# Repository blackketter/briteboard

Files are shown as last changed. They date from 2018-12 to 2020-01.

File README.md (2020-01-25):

# briteboard

BriteBoard is a Teensy 3.6-based keyboard with:

- 5x14 key matrix
- LCD display with capacitive touchscreen
- Audio amplifier and speaker
- USB host port for external mouse or keyboard
- Ambient light sensor

Runs the [britepad](https://github.com/blackketter/britepad) software.

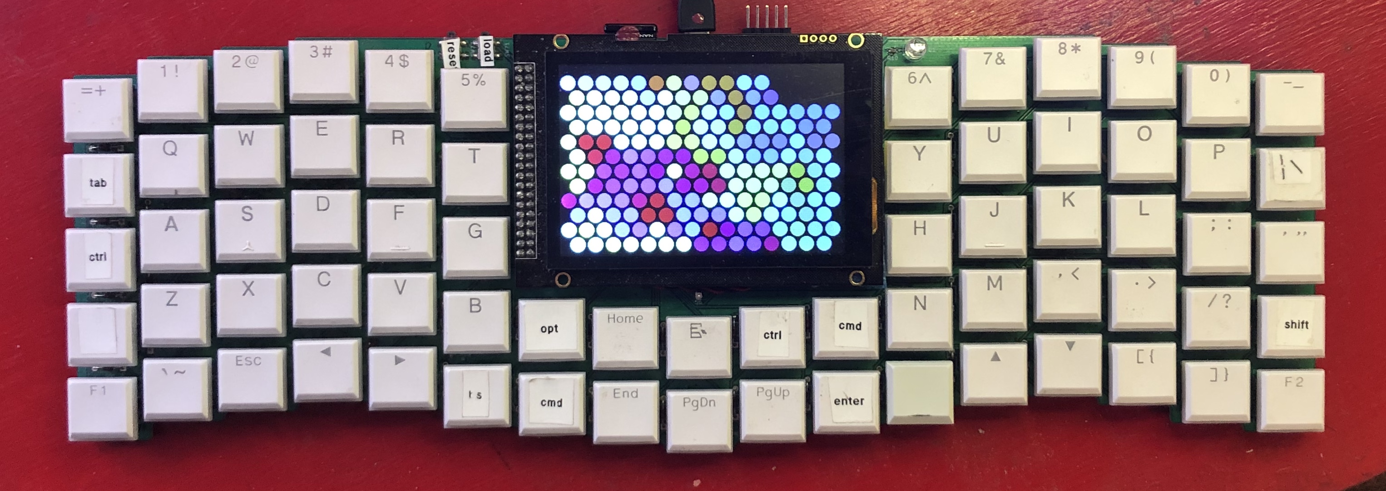
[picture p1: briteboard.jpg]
briteboard photo

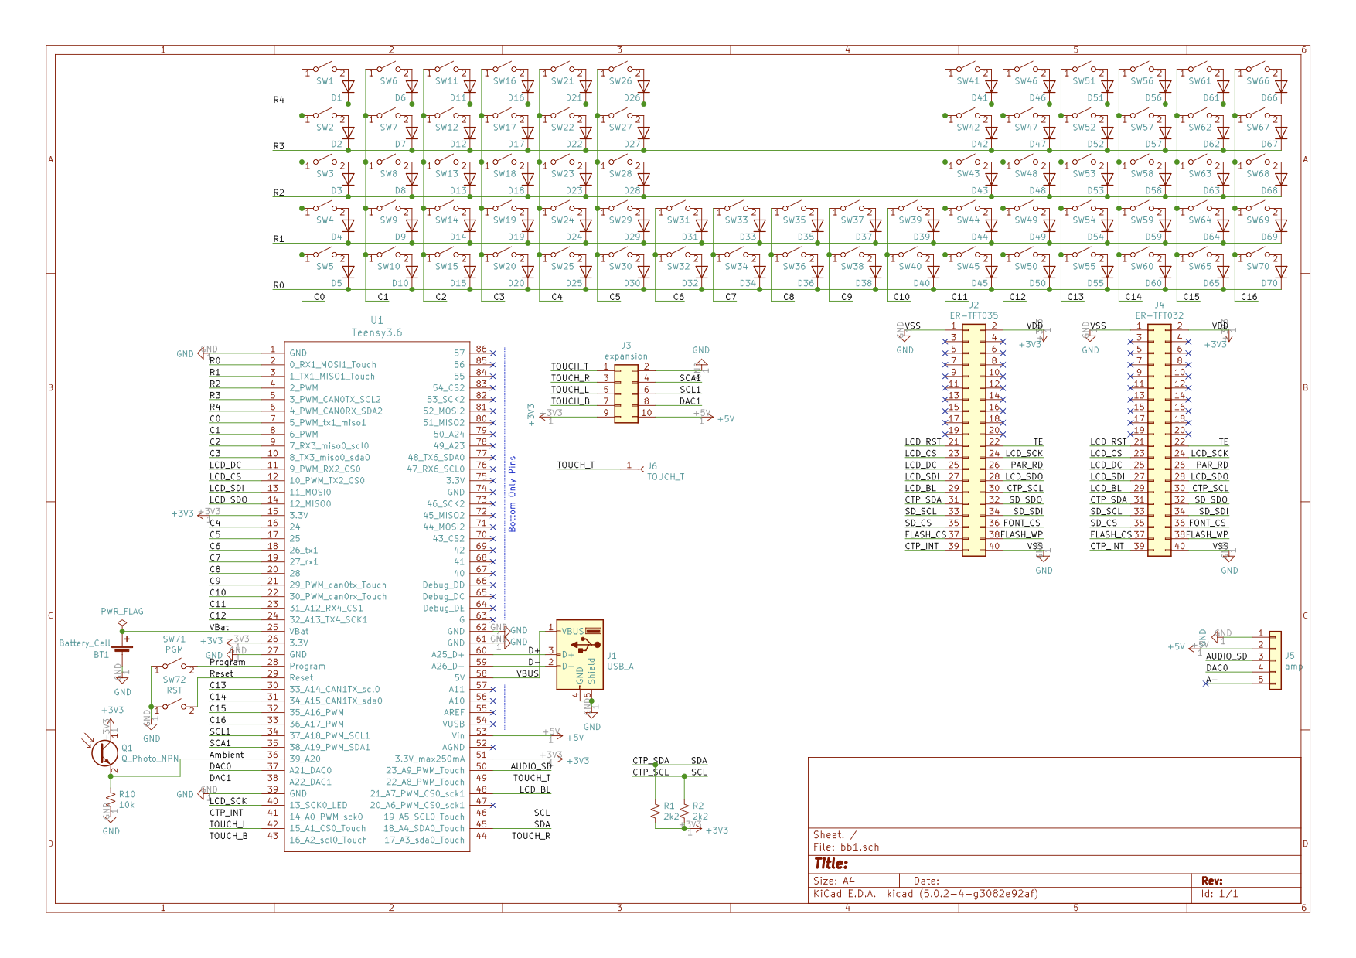
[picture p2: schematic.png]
schematic

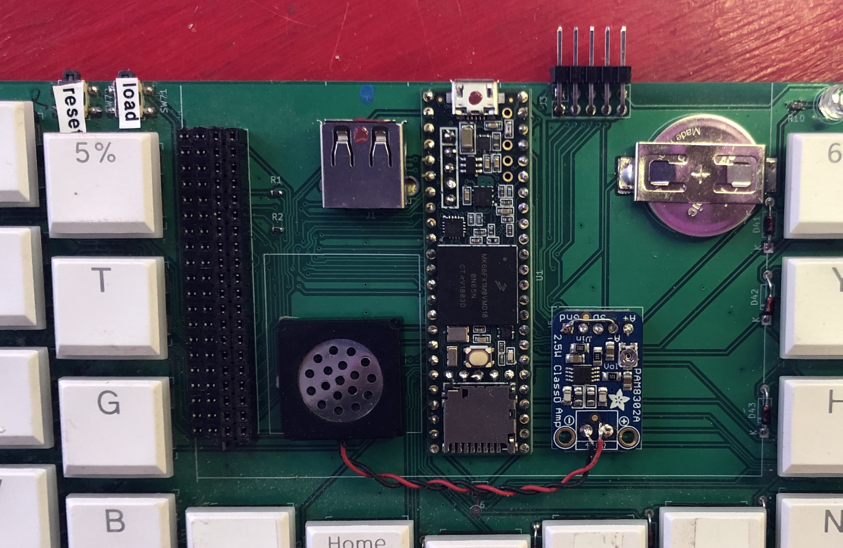
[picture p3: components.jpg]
components

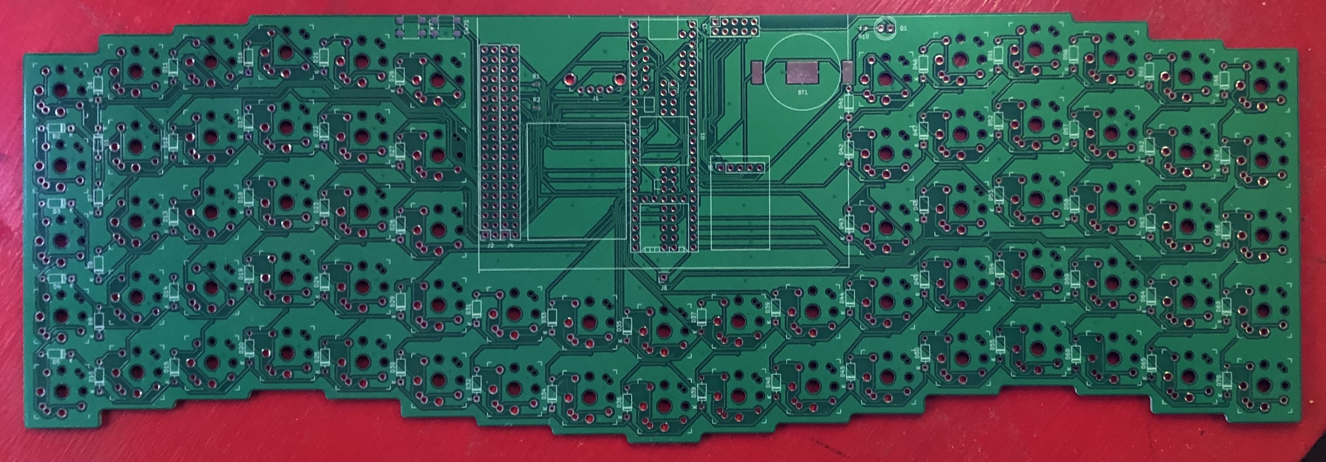
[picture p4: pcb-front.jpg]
PCB front

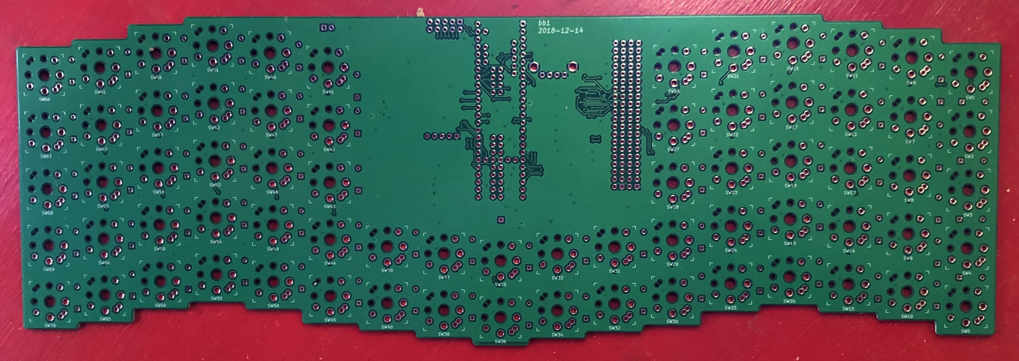
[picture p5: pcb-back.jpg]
PCB back


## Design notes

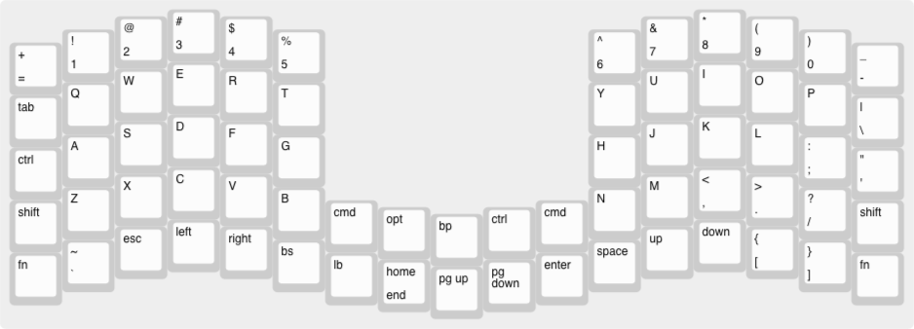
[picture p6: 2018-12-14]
bb-4.png

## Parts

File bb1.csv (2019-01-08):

Reference | Value | Footprint | Datasheet
SW1 | SW_SPST | keyswitches:PG1350_rotatable
D1 | 1N914 | Diode_THT:D_DO-35_SOD27_P7.62mm_Horizontal | http://www.vishay.com/docs/85622/1n914.pdf
SW2 | SW_SPST | keyswitches:PG1350_rotatable
D2 | 1N914 | Diode_THT:D_DO-35_SOD27_P7.62mm_Horizontal | http://www.vishay.com/docs/85622/1n914.pdf
SW3 | SW_SPST | keyswitches:PG1350_rotatable
D3 | 1N914 | Diode_THT:D_DO-35_SOD27_P7.62mm_Horizontal | http://www.vishay.com/docs/85622/1n914.pdf
SW4 | SW_SPST | keyswitches:PG1350_rotatable
D4 | 1N914 | Diode_THT:D_DO-35_SOD27_P7.62mm_Horizontal | http://www.vishay.com/docs/85622/1n914.pdf
SW5 | SW_SPST | keyswitches:PG1350_rotatable
D5 | 1N914 | Diode_THT:D_DO-35_SOD27_P7.62mm_Horizontal | http://www.vishay.com/docs/85622/1n914.pdf
SW6 | SW_SPST | keyswitches:PG1350_rotatable
D6 | 1N914 | Diode_THT:D_DO-35_SOD27_P7.62mm_Horizontal | http://www.vishay.com/docs/85622/1n914.pdf
SW7 | SW_SPST | keyswitches:PG1350_rotatable
D7 | 1N914 | Diode_THT:D_DO-35_SOD27_P7.62mm_Horizontal | http://www.vishay.com/docs/85622/1n914.pdf
SW8 | SW_SPST | keyswitches:PG1350_rotatable
D8 | 1N914 | Diode_THT:D_DO-35_SOD27_P7.62mm_Horizontal | http://www.vishay.com/docs/85622/1n914.pdf
SW9 | SW_SPST | keyswitches:PG1350_rotatable
D9 | 1N914 | Diode_THT:D_DO-35_SOD27_P7.62mm_Horizontal | http://www.vishay.com/docs/85622/1n914.pdf
SW10 | SW_SPST | keyswitches:PG1350_rotatable
D10 | 1N914 | Diode_THT:D_DO-35_SOD27_P7.62mm_Horizontal | http://www.vishay.com/docs/85622/1n914.pdf
SW11 | SW_SPST | keyswitches:PG1350_rotatable
D11 | 1N914 | Diode_THT:D_DO-35_SOD27_P7.62mm_Horizontal | http://www.vishay.com/docs/85622/1n914.pdf
SW12 | SW_SPST | keyswitches:PG1350_rotatable
D12 | 1N914 | Diode_THT:D_DO-35_SOD27_P7.62mm_Horizontal | http://www.vishay.com/docs/85622/1n914.pdf
SW13 | SW_SPST | keyswitches:PG1350_rotatable
D13 | 1N914 | Diode_THT:D_DO-35_SOD27_P7.62mm_Horizontal | http://www.vishay.com/docs/85622/1n914.pdf
SW14 | SW_SPST | keyswitches:PG1350_rotatable
D14 | 1N914 | Diode_THT:D_DO-35_SOD27_P7.62mm_Horizontal | http://www.vishay.com/docs/85622/1n914.pdf
SW15 | SW_SPST | keyswitches:PG1350_rotatable
D15 | 1N914 | Diode_THT:D_DO-35_SOD27_P7.62mm_Horizontal | http://www.vishay.com/docs/85622/1n914.pdf
SW16 | SW_SPST | keyswitches:PG1350_rotatable
D16 | 1N914 | Diode_THT:D_DO-35_SOD27_P7.62mm_Horizontal | http://www.vishay.com/docs/85622/1n914.pdf
SW17 | SW_SPST | keyswitches:PG1350_rotatable
D17 | 1N914 | Diode_THT:D_DO-35_SOD27_P7.62mm_Horizontal | http://www.vishay.com/docs/85622/1n914.pdf
SW18 | SW_SPST | keyswitches:PG1350_rotatable
D18 | 1N914 | Diode_THT:D_DO-35_SOD27_P7.62mm_Horizontal | http://www.vishay.com/docs/85622/1n914.pdf
SW19 | SW_SPST | keyswitches:PG1350_rotatable
D19 | 1N914 | Diode_THT:D_DO-35_SOD27_P7.62mm_Horizontal | http://www.vishay.com/docs/85622/1n914.pdf
SW20 | SW_SPST | keyswitches:PG1350_rotatable
D20 | 1N914 | Diode_THT:D_DO-35_SOD27_P7.62mm_Horizontal | http://www.vishay.com/docs/85622/1n914.pdf
SW21 | SW_SPST | keyswitches:PG1350_rotatable
D21 | 1N914 | Diode_THT:D_DO-35_SOD27_P7.62mm_Horizontal | http://www.vishay.com/docs/85622/1n914.pdf
SW22 | SW_SPST | keyswitches:PG1350_rotatable
D22 | 1N914 | Diode_THT:D_DO-35_SOD27_P7.62mm_Horizontal | http://www.vishay.com/docs/85622/1n914.pdf
SW23 | SW_SPST | keyswitches:PG1350_rotatable
D23 | 1N914 | Diode_THT:D_DO-35_SOD27_P7.62mm_Horizontal | http://www.vishay.com/docs/85622/1n914.pdf
SW24 | SW_SPST | keyswitches:PG1350_rotatable
D24 | 1N914 | Diode_THT:D_DO-35_SOD27_P7.62mm_Horizontal | http://www.vishay.com/docs/85622/1n914.pdf
SW25 | SW_SPST | keyswitches:PG1350_rotatable
D25 | 1N914 | Diode_THT:D_DO-35_SOD27_P7.62mm_Horizontal | http://www.vishay.com/docs/85622/1n914.pdf
SW26 | SW_SPST | keyswitches:PG1350_rotatable
D26 | 1N914 | Diode_THT:D_DO-35_SOD27_P7.62mm_Horizontal | http://www.vishay.com/docs/85622/1n914.pdf
SW27 | SW_SPST | keyswitches:PG1350_rotatable
D27 | 1N914 | Diode_THT:D_DO-35_SOD27_P7.62mm_Horizontal | http://www.vishay.com/docs/85622/1n914.pdf
SW28 | SW_SPST | keyswitches:PG1350_rotatable
D28 | 1N914 | Diode_THT:D_DO-35_SOD27_P7.62mm_Horizontal | http://www.vishay.com/docs/85622/1n914.pdf
SW29 | SW_SPST | keyswitches:PG1350_rotatable
D29 | 1N914 | Diode_THT:D_DO-35_SOD27_P7.62mm_Horizontal | http://www.vishay.com/docs/85622/1n914.pdf
SW30 | SW_SPST | keyswitches:PG1350_rotatable
D30 | 1N914 | Diode_THT:D_DO-35_SOD27_P7.62mm_Horizontal | http://www.vishay.com/docs/85622/1n914.pdf
SW31 | SW_SPST | keyswitches:PG1350_rotatable
D31 | 1N914 | Diode_THT:D_DO-35_SOD27_P7.62mm_Horizontal | http://www.vishay.com/docs/85622/1n914.pdf
SW32 | SW_SPST | keyswitches:PG1350_rotatable
D32 | 1N914 | Diode_THT:D_DO-35_SOD27_P7.62mm_Horizontal | http://www.vishay.com/docs/85622/1n914.pdf
SW33 | SW_SPST | keyswitches:PG1350_rotatable
D33 | 1N914 | Diode_THT:D_DO-35_SOD27_P7.62mm_Horizontal | http://www.vishay.com/docs/85622/1n914.pdf
SW34 | SW_SPST | keyswitches:PG1350_rotatable
D34 | 1N914 | Diode_THT:D_DO-35_SOD27_P7.62mm_Horizontal | http://www.vishay.com/docs/85622/1n914.pdf
SW35 | SW_SPST | keyswitches:PG1350_rotatable
D35 | 1N914 | Diode_THT:D_DO-35_SOD27_P7.62mm_Horizontal | http://www.vishay.com/docs/85622/1n914.pdf
SW36 | SW_SPST | keyswitches:PG1350_rotatable
D36 | 1N914 | Diode_THT:D_DO-35_SOD27_P7.62mm_Horizontal | http://www.vishay.com/docs/85622/1n914.pdf
SW37 | SW_SPST | keyswitches:PG1350_rotatable
D37 | 1N914 | Diode_THT:D_DO-35_SOD27_P7.62mm_Horizontal | http://www.vishay.com/docs/85622/1n914.pdf
SW38 | SW_SPST | keyswitches:PG1350_rotatable
D38 | 1N914 | Diode_THT:D_DO-35_SOD27_P7.62mm_Horizontal | http://www.vishay.com/docs/85622/1n914.pdf
SW39 | SW_SPST | keyswitches:PG1350_rotatable
D39 | 1N914 | Diode_THT:D_DO-35_SOD27_P7.62mm_Horizontal | http://www.vishay.com/docs/85622/1n914.pdf
SW40 | SW_SPST | keyswitches:PG1350_rotatable
D40 | 1N914 | Diode_THT:D_DO-35_SOD27_P7.62mm_Horizontal | http://www.vishay.com/docs/85622/1n914.pdf
SW41 | SW_SPST | keyswitches:PG1350_rotatable
D41 | 1N914 | Diode_THT:D_DO-35_SOD27_P7.62mm_Horizontal | http://www.vishay.com/docs/85622/1n914.pdf
SW42 | SW_SPST | keyswitches:PG1350_rotatable
D42 | 1N914 | Diode_THT:D_DO-35_SOD27_P7.62mm_Horizontal | http://www.vishay.com/docs/85622/1n914.pdf
SW43 | SW_SPST | keyswitches:PG1350_rotatable
D43 | 1N914 | Diode_THT:D_DO-35_SOD27_P7.62mm_Horizontal | http://www.vishay.com/docs/85622/1n914.pdf
SW44 | SW_SPST | keyswitches:PG1350_rotatable
D44 | 1N914 | Diode_THT:D_DO-35_SOD27_P7.62mm_Horizontal | http://www.vishay.com/docs/85622/1n914.pdf
SW45 | SW_SPST | keyswitches:PG1350_rotatable
D45 | 1N914 | Diode_THT:D_DO-35_SOD27_P7.62mm_Horizontal | http://www.vishay.com/docs/85622/1n914.pdf
SW46 | SW_SPST | keyswitches:PG1350_rotatable
D46 | 1N914 | Diode_THT:D_DO-35_SOD27_P7.62mm_Horizontal | http://www.vishay.com/docs/85622/1n914.pdf
SW47 | SW_SPST | keyswitches:PG1350_rotatable
D47 | 1N914 | Diode_THT:D_DO-35_SOD27_P7.62mm_Horizontal | http://www.vishay.com/docs/85622/1n914.pdf
SW48 | SW_SPST | keyswitches:PG1350_rotatable
D48 | 1N914 | Diode_THT:D_DO-35_SOD27_P7.62mm_Horizontal | http://www.vishay.com/docs/85622/1n914.pdf
SW49 | SW_SPST | keyswitches:PG1350_rotatable
D49 | 1N914 | Diode_THT:D_DO-35_SOD27_P7.62mm_Horizontal | http://www.vishay.com/docs/85622/1n914.pdf
SW50 | SW_SPST | keyswitches:PG1350_rotatable
D50 | 1N914 | Diode_THT:D_DO-35_SOD27_P7.62mm_Horizontal | http://www.vishay.com/docs/85622/1n914.pdf
SW51 | SW_SPST | keyswitches:PG1350_rotatable
D51 | 1N914 | Diode_THT:D_DO-35_SOD27_P7.62mm_Horizontal | http://www.vishay.com/docs/85622/1n914.pdf
SW52 | SW_SPST | keyswitches:PG1350_rotatable
D52 | 1N914 | Diode_THT:D_DO-35_SOD27_P7.62mm_Horizontal | http://www.vishay.com/docs/85622/1n914.pdf
SW53 | SW_SPST | keyswitches:PG1350_rotatable
D53 | 1N914 | Diode_THT:D_DO-35_SOD27_P7.62mm_Horizontal | http://www.vishay.com/docs/85622/1n914.pdf
SW54 | SW_SPST | keyswitches:PG1350_rotatable
D54 | 1N914 | Diode_THT:D_DO-35_SOD27_P7.62mm_Horizontal | http://www.vishay.com/docs/85622/1n914.pdf
SW55 | SW_SPST | keyswitches:PG1350_rotatable
D55 | 1N914 | Diode_THT:D_DO-35_SOD27_P7.62mm_Horizontal | http://www.vishay.com/docs/85622/1n914.pdf
SW56 | SW_SPST | keyswitches:PG1350_rotatable
D56 | 1N914 | Diode_THT:D_DO-35_SOD27_P7.62mm_Horizontal | http://www.vishay.com/docs/85622/1n914.pdf
SW57 | SW_SPST | keyswitches:PG1350_rotatable
D57 | 1N914 | Diode_THT:D_DO-35_SOD27_P7.62mm_Horizontal | http://www.vishay.com/docs/85622/1n914.pdf
SW58 | SW_SPST | keyswitches:PG1350_rotatable
D58 | 1N914 | Diode_THT:D_DO-35_SOD27_P7.62mm_Horizontal | http://www.vishay.com/docs/85622/1n914.pdf
SW59 | SW_SPST | keyswitches:PG1350_rotatable
D59 | 1N914 | Diode_THT:D_DO-35_SOD27_P7.62mm_Horizontal | http://www.vishay.com/docs/85622/1n914.pdf
SW60 | SW_SPST | keyswitches:PG1350_rotatable
D60 | 1N914 | Diode_THT:D_DO-35_SOD27_P7.62mm_Horizontal | http://www.vishay.com/docs/85622/1n914.pdf
SW61 | SW_SPST | keyswitches:PG1350_rotatable
D61 | 1N914 | Diode_THT:D_DO-35_SOD27_P7.62mm_Horizontal | http://www.vishay.com/docs/85622/1n914.pdf
SW62 | SW_SPST | keyswitches:PG1350_rotatable
D62 | 1N914 | Diode_THT:D_DO-35_SOD27_P7.62mm_Horizontal | http://www.vishay.com/docs/85622/1n914.pdf
SW63 | SW_SPST | keyswitches:PG1350_rotatable
D63 | 1N914 | Diode_THT:D_DO-35_SOD27_P7.62mm_Horizontal | http://www.vishay.com/docs/85622/1n914.pdf
SW64 | SW_SPST | keyswitches:PG1350_rotatable
D64 | 1N914 | Diode_THT:D_DO-35_SOD27_P7.62mm_Horizontal | http://www.vishay.com/docs/85622/1n914.pdf
SW65 | SW_SPST | keyswitches:PG1350_rotatable
D65 | 1N914 | Diode_THT:D_DO-35_SOD27_P7.62mm_Horizontal | http://www.vishay.com/docs/85622/1n914.pdf
SW66 | SW_SPST | keyswitches:PG1350_rotatable
D66 | 1N914 | Diode_THT:D_DO-35_SOD27_P7.62mm_Horizontal | http://www.vishay.com/docs/85622/1n914.pdf
SW67 | SW_SPST | keyswitches:PG1350_rotatable
D67 | 1N914 | Diode_THT:D_DO-35_SOD27_P7.62mm_Horizontal | http://www.vishay.com/docs/85622/1n914.pdf
SW68 | SW_SPST | keyswitches:PG1350_rotatable
D68 | 1N914 | Diode_THT:D_DO-35_SOD27_P7.62mm_Horizontal | http://www.vishay.com/docs/85622/1n914.pdf
SW69 | SW_SPST | keyswitches:PG1350_rotatable
D69 | 1N914 | Diode_THT:D_DO-35_SOD27_P7.62mm_Horizontal | http://www.vishay.com/docs/85622/1n914.pdf
SW70 | SW_SPST | keyswitches:PG1350_rotatable
D70 | 1N914 | Diode_THT:D_DO-35_SOD27_P7.62mm_Horizontal | http://www.vishay.com/docs/85622/1n914.pdf
U1 | Teensy3.6 | teensy:Teensy35_36
J2 | ER-TFT035 | Connector_PinSocket_2.54mm:PinSocket_2x20_P2.54mm_Vertical | ~
BT1 | Battery_Cell | BC-2003:BC-2003 | ~
J1 | USB_A | digikey-footprints:USB_A_Female_UE27AC54100 | ~
SW71 | PGM | EVQPSL:EVQPSL
SW72 | RST | EVQPSL:EVQPSL
R1 | 2k2 | digikey-footprints:0603 | ~
R2 | 2k2 | digikey-footprints:0603 | ~
J4 | ER-TFT032 | Connector_PinSocket_2.54mm:PinSocket_2x20_P2.54mm_Vertical | ~
J5 | amp | Connector_PinSocket_2.54mm:PinSocket_1x05_P2.54mm_Vertical | ~
Q1 | Q_Photo_NPN | LED_THT:LED_D5.0mm_FlatTop | ~
R10 | 10k | digikey-footprints:0603 | ~
J3 | expansion | Connector_PinSocket_2.54mm:PinSocket_2x05_P2.54mm_Vertical | ~
J6 | TOUCH_T | Connector_PinSocket_2.54mm:PinSocket_1x01_P2.54mm_Vertical | ~

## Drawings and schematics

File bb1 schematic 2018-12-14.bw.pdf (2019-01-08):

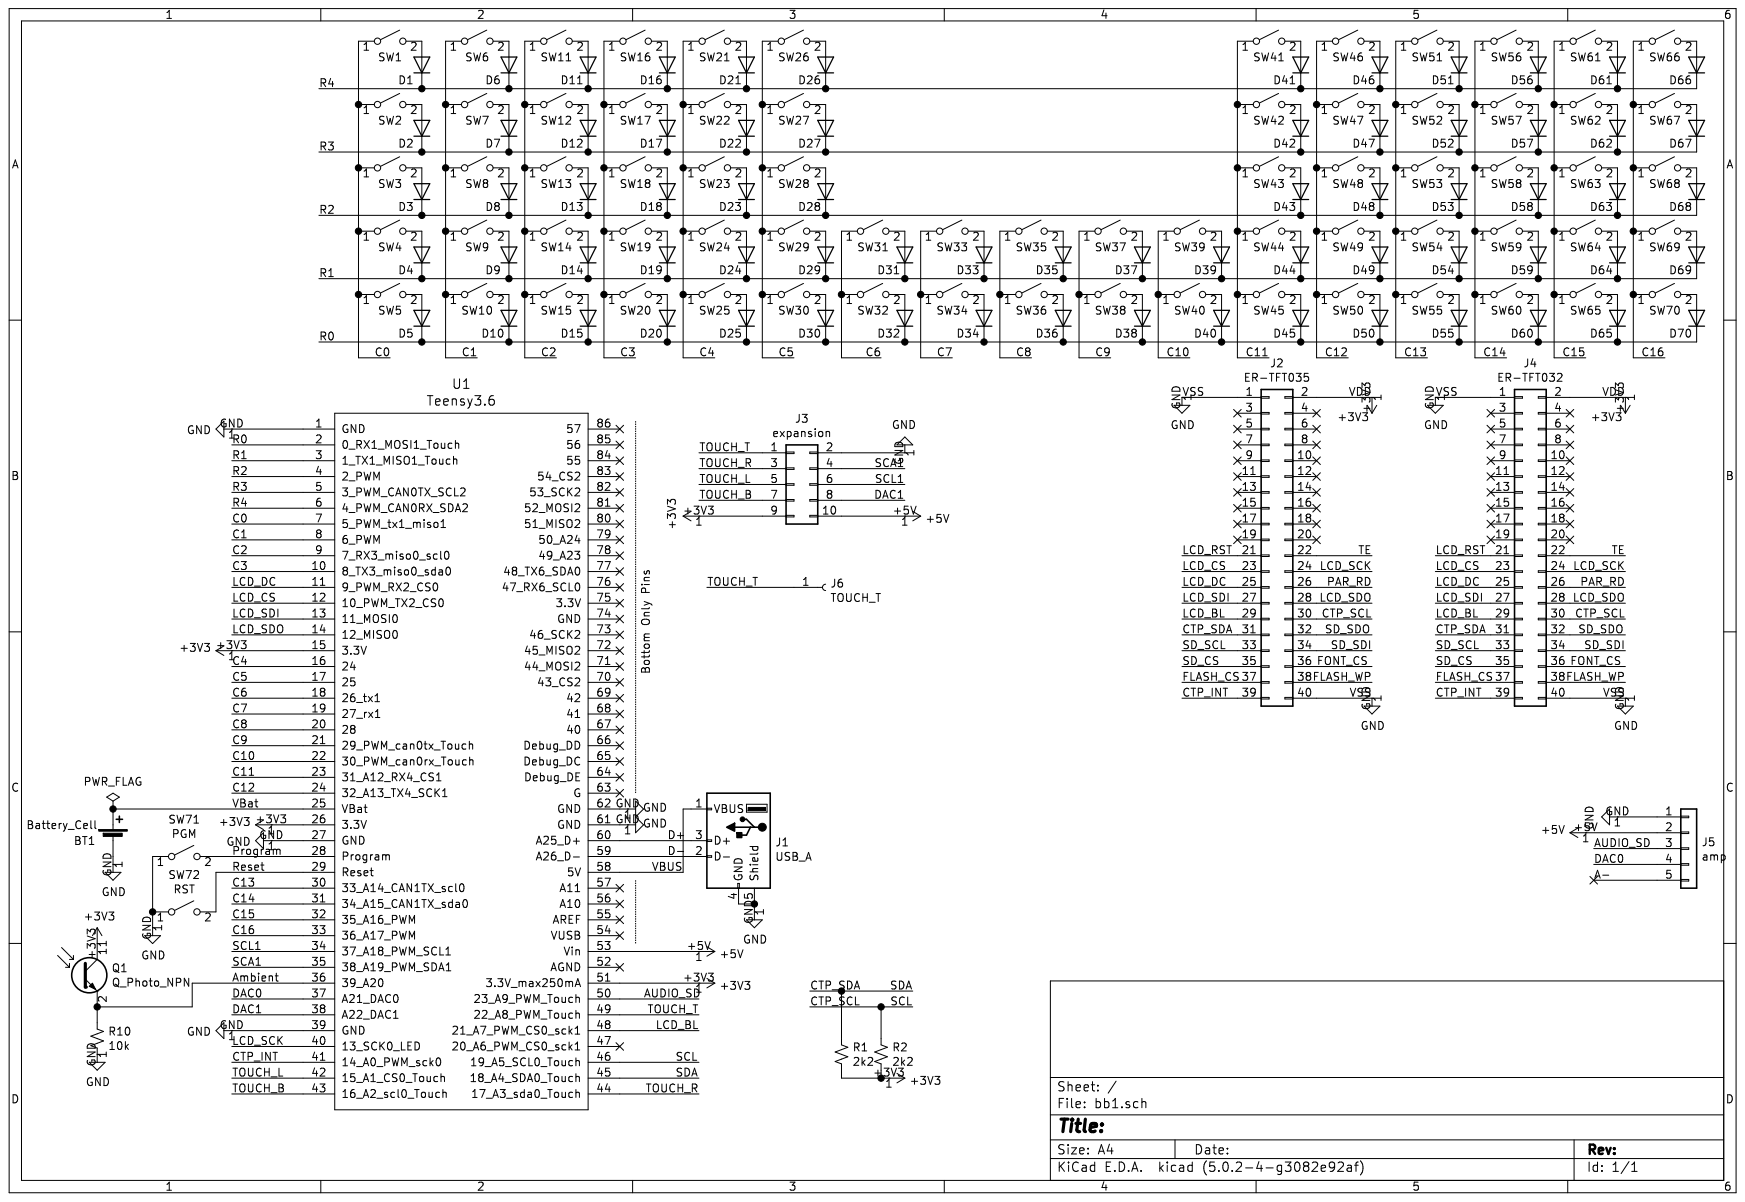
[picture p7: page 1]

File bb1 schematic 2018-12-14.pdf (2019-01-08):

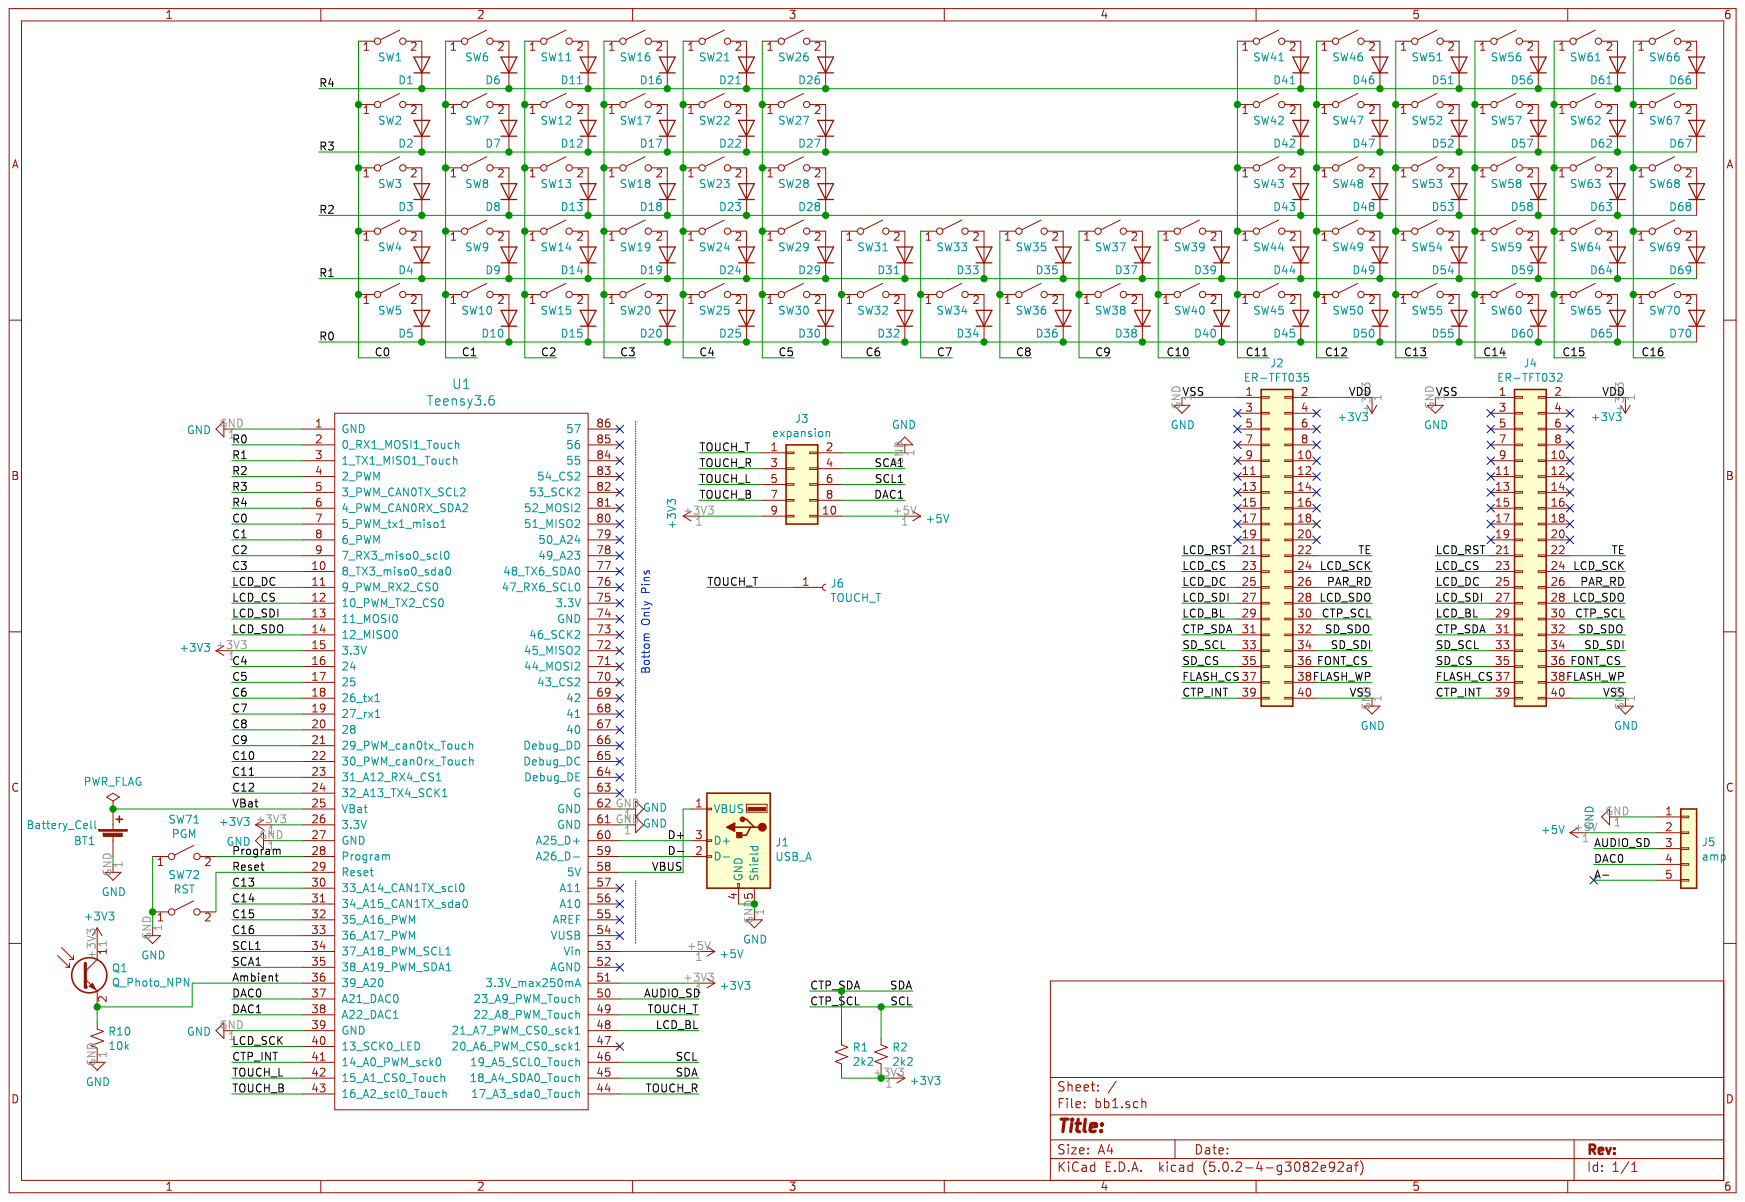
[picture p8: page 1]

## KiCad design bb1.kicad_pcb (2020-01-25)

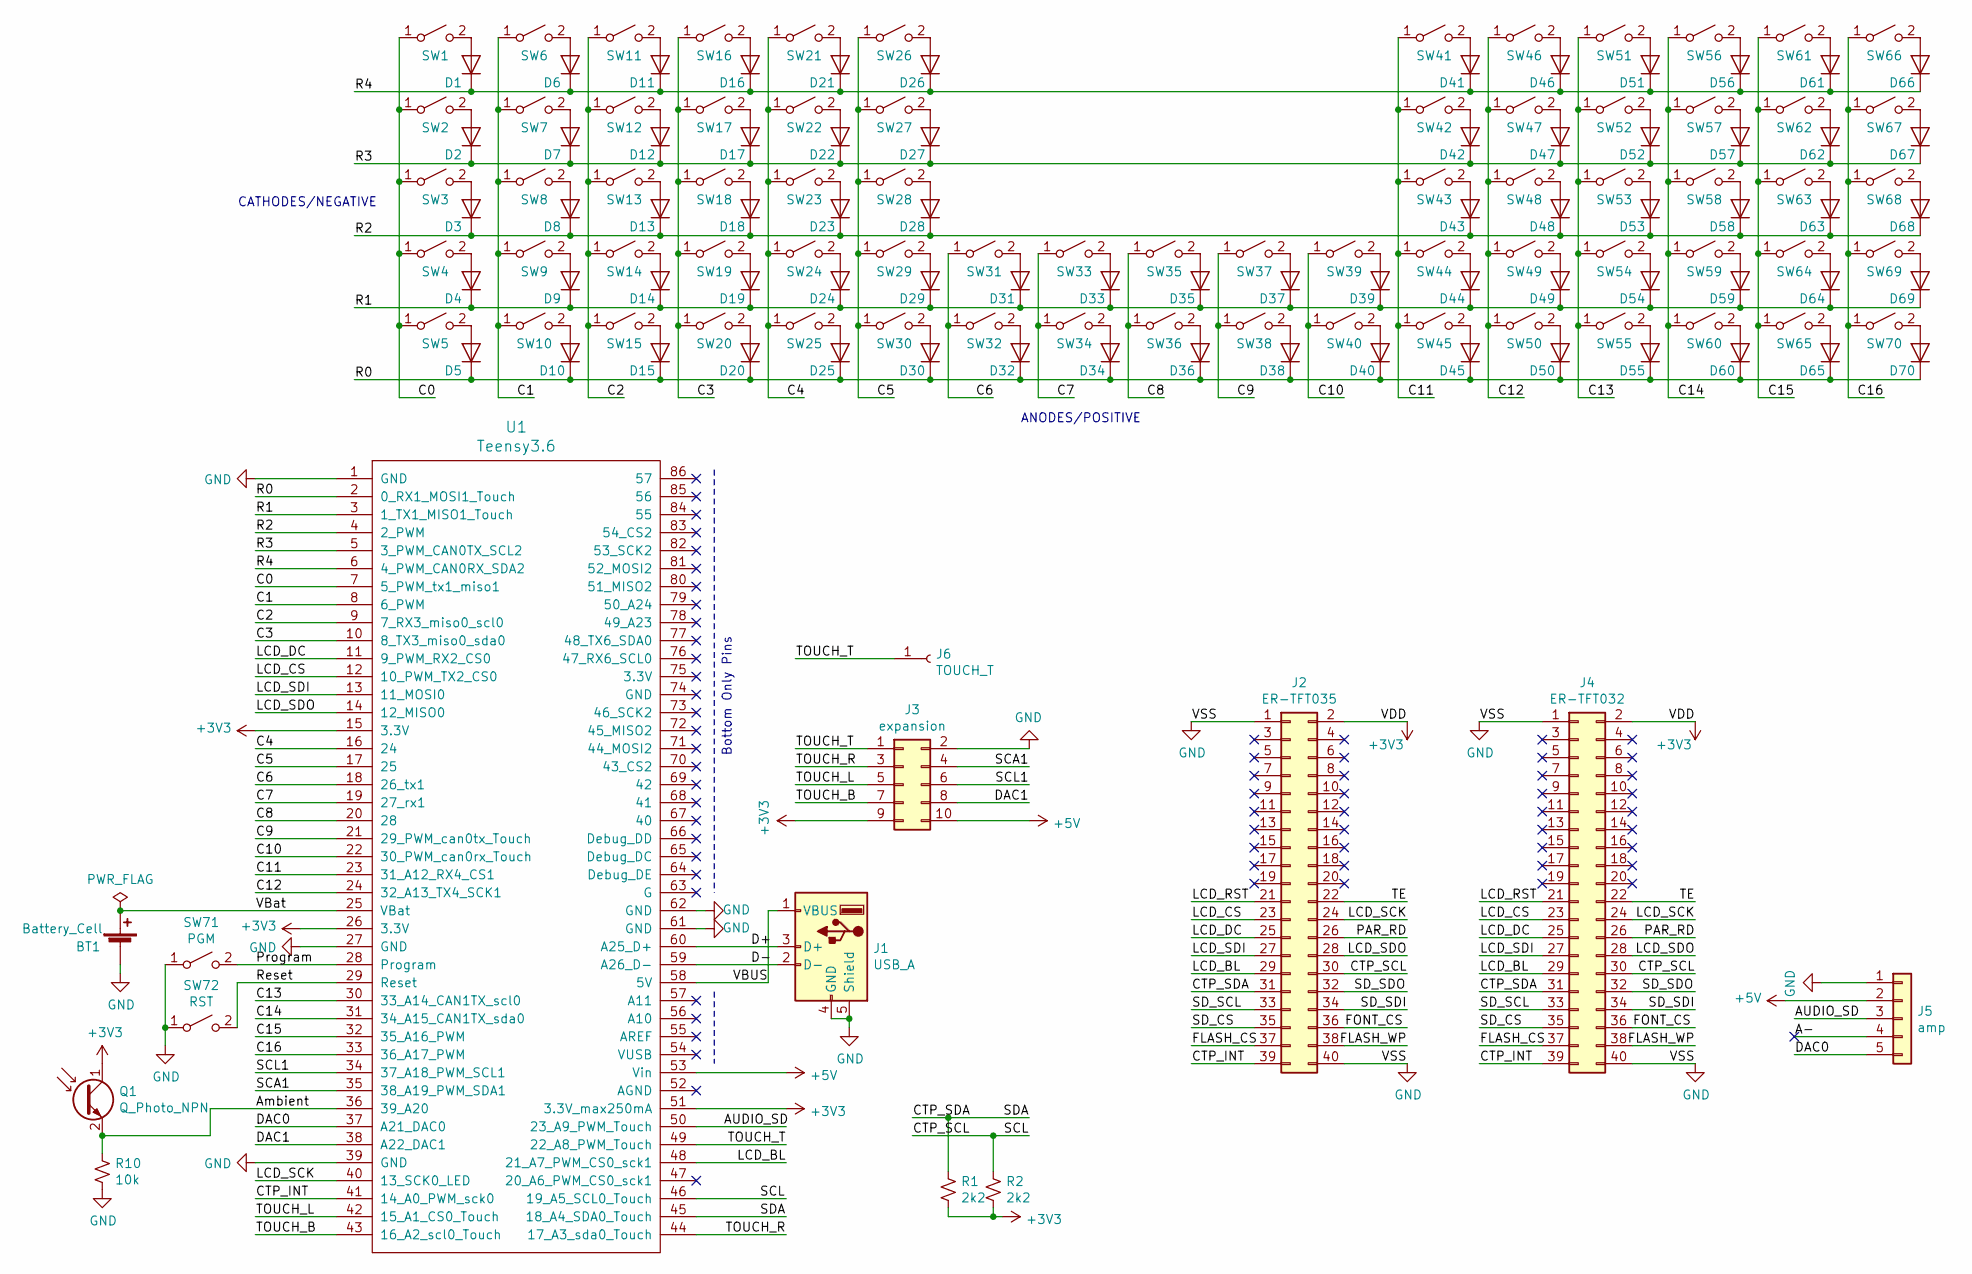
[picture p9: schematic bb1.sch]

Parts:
BT1: Battery_Cell; BC-2003
D1, D2, D3, D4, D5, D6, D7, D8, D9, D10, D11, D12, D13, D14, D15, D16, D17, D18, D19, D20, D21, D22, D23, D24, D25, D26, D27, D28, D29, D30, D31, D32, D33, D34, D35, D36, D37, D38, D39, D40, D41, D42, D43, D44, D45, D46, D47, D48, D49, D50, D51, D52, D53, D54, D55, D56, D57, D58, D59, D60, D61, D62, D63, D64, D65, D66, D67, D68, D69, D70: 1N914; D_DO-35_SOD27_P7.62mm_Horizontal
J1: USB_A; USB_A_Female_UE27AC54100
J2: ER-TFT035; PinSocket_2x20_P2.54mm_Vertical
J3: expansion; PinSocket_2x05_P2.54mm_Vertical
J4: ER-TFT032; PinSocket_2x20_P2.54mm_Vertical
J5: amp; PinSocket_1x05_P2.54mm_Vertical
J6: TOUCH_T; PinSocket_1x01_P2.54mm_Vertical
Q1: Q_Photo_NPN; LED_D5.0mm_FlatTop
R1, R2: 2k2; 0603
R10: 10k; 0603
SW1, SW2, SW3, SW4, SW5, SW6, SW7, SW8, SW9, SW10, SW11, SW12, SW13, SW14, SW15, SW16, SW17, SW18, SW19, SW20, SW21, SW22, SW23, SW24, SW25, SW26, SW27, SW28, SW29, SW30, SW31, SW32, SW33, SW34, SW35, SW36, SW37, SW38, SW39, SW40, SW41, SW42, SW43, SW44, SW45, SW46, SW47, SW48, SW49, SW50, SW51, SW52, SW53, SW54, SW55, SW56, SW57, SW58, SW59, SW60, SW61, SW62, SW63, SW64, SW65, SW66, SW67, SW68, SW69, SW70: SW_SPST; PG1350_rotatable
SW71: PGM; EVQPSL
SW72: RST; EVQPSL
U1: Teensy3.6; Teensy35_36

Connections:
+3V3: J2.2, J3.9, J4.2, Q1.1 (C), R1.2, R2.2, U1.15 (3.3V), U1.26 (3.3V), U1.51 (3.3V_max250mA)
+5V: J3.10, J5.2, U1.53 (Vin)
/AUDIO_SD: J5.3, U1.50 (23_A9_PWM_Touch)
/Ambient: Q1.2 (E), R10.1, U1.36 (39_A20)
/C0: SW1.1 (A), SW2.1 (A), SW3.1 (A), SW4.1 (A), SW5.1 (A), U1.7 (5_PWM_tx1_miso1)
/C1: SW6.1 (A), SW7.1 (A), SW8.1 (A), SW9.1 (A), SW10.1 (A), U1.8 (6_PWM)
/C2: SW11.1 (A), SW12.1 (A), SW13.1 (A), SW14.1 (A), SW15.1 (A), U1.9 (7_RX3_miso0_scl0)
/C3: SW16.1 (A), SW17.1 (A), SW18.1 (A), SW19.1 (A), SW20.1 (A), U1.10 (8_TX3_miso0_sda0)
/C4: SW21.1 (A), SW22.1 (A), SW23.1 (A), SW24.1 (A), SW25.1 (A), U1.16 (24)
/C5: SW26.1 (A), SW27.1 (A), SW28.1 (A), SW29.1 (A), SW30.1 (A), U1.17 (25)
/C6: SW31.1 (A), SW32.1 (A), U1.18 (26_tx1)
/C7: SW33.1 (A), SW34.1 (A), U1.19 (27_rx1)
/C8: SW35.1 (A), SW36.1 (A), U1.20 (28)
/C9: SW37.1 (A), SW38.1 (A), U1.21 (29_PWM_can0tx_Touch)
/C10: SW39.1 (A), SW40.1 (A), U1.22 (30_PWM_can0rx_Touch)
/C11: SW41.1 (A), SW42.1 (A), SW43.1 (A), SW44.1 (A), SW45.1 (A), U1.23 (31_A12_RX4_CS1)
/C12: SW46.1 (A), SW47.1 (A), SW48.1 (A), SW49.1 (A), SW50.1 (A), U1.24 (32_A13_TX4_SCK1)
/C13: SW51.1 (A), SW52.1 (A), SW53.1 (A), SW54.1 (A), SW55.1 (A), U1.30 (33_A14_CAN1TX_scl0)
/C14: SW56.1 (A), SW57.1 (A), SW58.1 (A), SW59.1 (A), SW60.1 (A), U1.31 (34_A15_CAN1TX_sda0)
/C15: SW61.1 (A), SW62.1 (A), SW63.1 (A), SW64.1 (A), SW65.1 (A), U1.32 (35_A16_PWM)
/C16: SW66.1 (A), SW67.1 (A), SW68.1 (A), SW69.1 (A), SW70.1 (A), U1.33 (36_A17_PWM)
/CTP_INT: J2.39, J4.39, U1.41 (14_A0_PWM_sck0)
/CTP_SCL: J2.30, J4.30, R2.1, U1.46 (19_A5_SCL0_Touch)
/CTP_SDA: J2.31, J4.31, R1.1, U1.45 (18_A4_SDA0_Touch)
/D+: J1.3 (D+), U1.60 (A25_D+)
/D-: J1.2 (D-), U1.59 (A26_D-)
/DAC0: J5.5, U1.37 (A21_DAC0)
/DAC1: J3.8, U1.38 (A22_DAC1)
/FLASH_CS: J2.37, J4.37
/FLASH_WP: J2.38, J4.38
/FONT_CS: J2.36, J4.36
/LCD_BL: J2.29, J4.29, U1.48 (21_A7_PWM_CS0_sck1)
/LCD_CS: J2.23, J4.23, U1.12 (10_PWM_TX2_CS0)
/LCD_DC: J2.25, J4.25, U1.11 (9_PWM_RX2_CS0)
/LCD_RST: J2.21, J4.21
/LCD_SCK: J2.24, J4.24, U1.40 (13_SCK0_LED)
/LCD_SDI: J2.27, J4.27, U1.13 (11_MOSI0)
/LCD_SDO: J2.28, J4.28, U1.14 (12_MISO0)
/PAR_RD: J2.26, J4.26
/Program: SW71.2 (B), U1.28 (Program)
/R0: D5.1 (K), D10.1 (K), D15.1 (K), D20.1 (K), D25.1 (K), D30.1 (K), D32.1 (K), D34.1 (K), D36.1 (K), D38.1 (K), D40.1 (K), D45.1 (K), D50.1 (K), D55.1 (K), D60.1 (K), D65.1 (K), D70.1 (K), U1.2 (0_RX1_MOSI1_Touch)
/R1: D4.1 (K), D9.1 (K), D14.1 (K), D19.1 (K), D24.1 (K), D29.1 (K), D31.1 (K), D33.1 (K), D35.1 (K), D37.1 (K), D39.1 (K), D44.1 (K), D49.1 (K), D54.1 (K), D59.1 (K), D64.1 (K), D69.1 (K), U1.3 (1_TX1_MISO1_Touch)
/R2: D3.1 (K), D8.1 (K), D13.1 (K), D18.1 (K), D23.1 (K), D28.1 (K), D43.1 (K), D48.1 (K), D53.1 (K), D58.1 (K), D63.1 (K), D68.1 (K), U1.4 (2_PWM)
/R3: D2.1 (K), D7.1 (K), D12.1 (K), D17.1 (K), D22.1 (K), D27.1 (K), D42.1 (K), D47.1 (K), D52.1 (K), D57.1 (K), D62.1 (K), D67.1 (K), U1.5 (3_PWM_CAN0TX_SCL2)
/R4: D1.1 (K), D6.1 (K), D11.1 (K), D16.1 (K), D21.1 (K), D26.1 (K), D41.1 (K), D46.1 (K), D51.1 (K), D56.1 (K), D61.1 (K), D66.1 (K), U1.6 (4_PWM_CAN0RX_SDA2)
/Reset: SW72.2 (B), U1.29 (Reset)
/SCA1: J3.4, U1.35 (38_A19_PWM_SDA1)
/SCL1: J3.6, U1.34 (37_A18_PWM_SCL1)
/SD_CS: J2.35, J4.35
/SD_SCL: J2.33, J4.33
/SD_SDI: J2.34, J4.34
/SD_SDO: J2.32, J4.32
/TE: J2.22, J4.22
/TOUCH_B: J3.7, U1.43 (16_A2_scl0_Touch)
/TOUCH_L: J3.5, U1.42 (15_A1_CS0_Touch)
/TOUCH_R: J3.3, U1.44 (17_A3_sda0_Touch)
/TOUCH_T: J3.1, J6.1, U1.49 (22_A8_PWM_Touch)
/VBUS: J1.1 (VBUS), U1.58 (5V)
/VBat: BT1.1 (+), U1.25 (VBat)
GND: BT1.2 (-), J1.4 (GND), J1.5 (Shield), J2.1, J2.40, J3.2, J4.1, J4.40, J5.1, R10.2, SW71.1 (A), SW72.1 (A), U1.1 (GND), U1.27 (GND), U1.39 (GND), U1.61 (GND), U1.62 (GND)
unnamed: D1.2 (A), SW1.2 (B)
unnamed: D2.2 (A), SW2.2 (B)
unnamed: D3.2 (A), SW3.2 (B)
unnamed: D4.2 (A), SW4.2 (B)
unnamed: D5.2 (A), SW5.2 (B)
unnamed: D6.2 (A), SW6.2 (B)
unnamed: D7.2 (A), SW7.2 (B)
unnamed: D8.2 (A), SW8.2 (B)
unnamed: D9.2 (A), SW9.2 (B)
unnamed: D10.2 (A), SW10.2 (B)
unnamed: D11.2 (A), SW11.2 (B)
unnamed: D12.2 (A), SW12.2 (B)
unnamed: D13.2 (A), SW13.2 (B)
unnamed: D14.2 (A), SW14.2 (B)
unnamed: D15.2 (A), SW15.2 (B)
unnamed: D16.2 (A), SW16.2 (B)
unnamed: D17.2 (A), SW17.2 (B)
unnamed: D18.2 (A), SW18.2 (B)
unnamed: D19.2 (A), SW19.2 (B)
unnamed: D20.2 (A), SW20.2 (B)
unnamed: D21.2 (A), SW21.2 (B)
unnamed: D22.2 (A), SW22.2 (B)
unnamed: D23.2 (A), SW23.2 (B)
unnamed: D24.2 (A), SW24.2 (B)
unnamed: D25.2 (A), SW25.2 (B)
unnamed: D26.2 (A), SW26.2 (B)
unnamed: D27.2 (A), SW27.2 (B)
unnamed: D28.2 (A), SW28.2 (B)
unnamed: D29.2 (A), SW29.2 (B)
unnamed: D30.2 (A), SW30.2 (B)
unnamed: D31.2 (A), SW31.2 (B)
unnamed: D32.2 (A), SW32.2 (B)
unnamed: D33.2 (A), SW33.2 (B)
unnamed: D34.2 (A), SW34.2 (B)
unnamed: D35.2 (A), SW35.2 (B)
unnamed: D36.2 (A), SW36.2 (B)
unnamed: D37.2 (A), SW37.2 (B)
unnamed: D38.2 (A), SW38.2 (B)
unnamed: D39.2 (A), SW39.2 (B)
unnamed: D40.2 (A), SW40.2 (B)
unnamed: D41.2 (A), SW41.2 (B)
unnamed: D42.2 (A), SW42.2 (B)
unnamed: D43.2 (A), SW43.2 (B)
unnamed: D44.2 (A), SW44.2 (B)
unnamed: D45.2 (A), SW45.2 (B)
unnamed: D46.2 (A), SW46.2 (B)
unnamed: D47.2 (A), SW47.2 (B)
unnamed: D48.2 (A), SW48.2 (B)
unnamed: D49.2 (A), SW49.2 (B)
unnamed: D50.2 (A), SW50.2 (B)
unnamed: D51.2 (A), SW51.2 (B)
unnamed: D52.2 (A), SW52.2 (B)
unnamed: D53.2 (A), SW53.2 (B)
unnamed: D54.2 (A), SW54.2 (B)
unnamed: D55.2 (A), SW55.2 (B)
unnamed: D56.2 (A), SW56.2 (B)
unnamed: D57.2 (A), SW57.2 (B)
unnamed: D58.2 (A), SW58.2 (B)
unnamed: D59.2 (A), SW59.2 (B)
unnamed: D60.2 (A), SW60.2 (B)
unnamed: D61.2 (A), SW61.2 (B)
unnamed: D62.2 (A), SW62.2 (B)
unnamed: D63.2 (A), SW63.2 (B)
unnamed: D64.2 (A), SW64.2 (B)
unnamed: D65.2 (A), SW65.2 (B)
unnamed: D66.2 (A), SW66.2 (B)
unnamed: D67.2 (A), SW67.2 (B)
unnamed: D68.2 (A), SW68.2 (B)
unnamed: D69.2 (A), SW69.2 (B)
unnamed: D70.2 (A), SW70.2 (B)

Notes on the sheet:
Bottom Only Pins
ANODES/POSITIVE
CATHODES/NEGATIVE

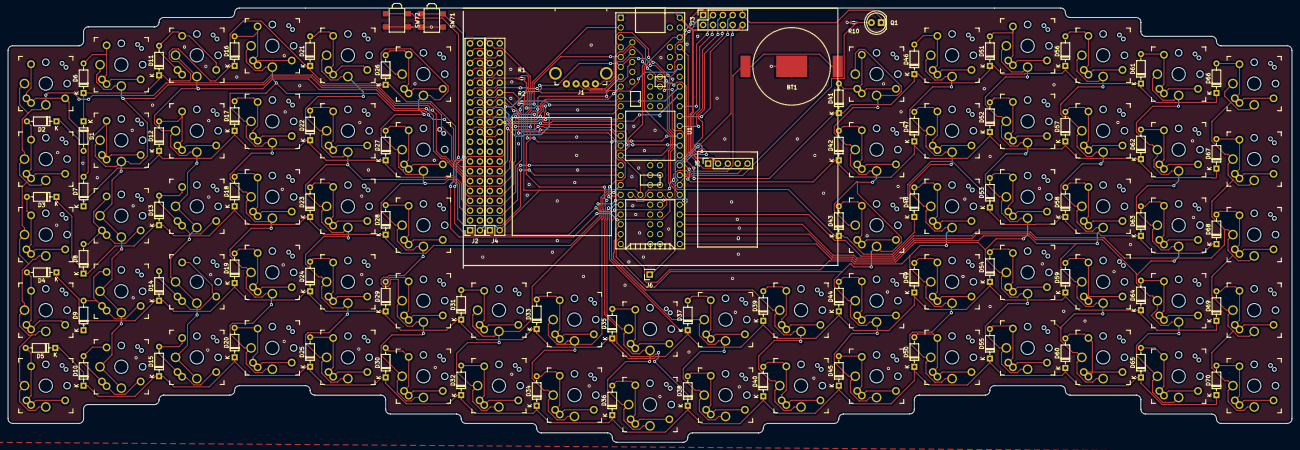
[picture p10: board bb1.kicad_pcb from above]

Board: 2 copper layers, 331.5 x 112.1 mm, 154 parts (0 on the bottom side), 130 nets.

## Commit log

2018-12-14 First pass on bb1 pcb. Ordered via elecrow
    [bb1-B.Cu.gbr, bb1-B.Mask.gbr, bb1-B.SilkS.gbr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]
2018-12-14 Final save after order
    [bb1.kicad_pcb]
2019-01-08 Added schematics and datasheets
    [bb1.csv]
2020-01-25 Last changes, finally committed.
    [bb1.kicad_pcb, bb1.sch]
2020-01-25 Added README and BOM
